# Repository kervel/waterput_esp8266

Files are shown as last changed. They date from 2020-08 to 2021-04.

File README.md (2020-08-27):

# About

This is a simple breakout for an ESP12MOD module that enables easy connection to a 5V power supply and that converts 2 IOs to 5V levels, suitable for connecting an acoustic waterlevel sensor.

The software reads the acoustic waterlevel sensor 30 times and sends the median value via MQTT.

# The hardware

Following components are needed:
* the pcb's (Aisler template is used in pcb/ folder, so easiest to order via aisler)
* an ESP12MOD module (the one with 22 pins!)
* A SR04M-2 acoustic sensor or equivalent
* A LM1117T linear regulator in a TO-220-3 package
* 8 10Kohm 0805 resistors
* 2 BSS138 mosfets in SOT-23 package
* A screw terminal block with 2 connections pitch 3.5mm
* A 0.1μF radial electrolytic capacitor, diameter 4mm, pitch 2mm
* 2 10μF radial electrolytic capacitors, diameter 4mm, pitch 2mm
* female pin header, 6 pins, 2.54mm pitch
* male pin header, 4 pins, 2.54mm pitch for reset/program jumper (optional)
* a jumper or a jumper cable (optional)

To connect the acoustic sensor, note that the `TRG` pin might be called `RX`
and the `ECHO` pin might be called `TX`. This is because some boards can be
configured to operate in serial mode by adding a resistor.

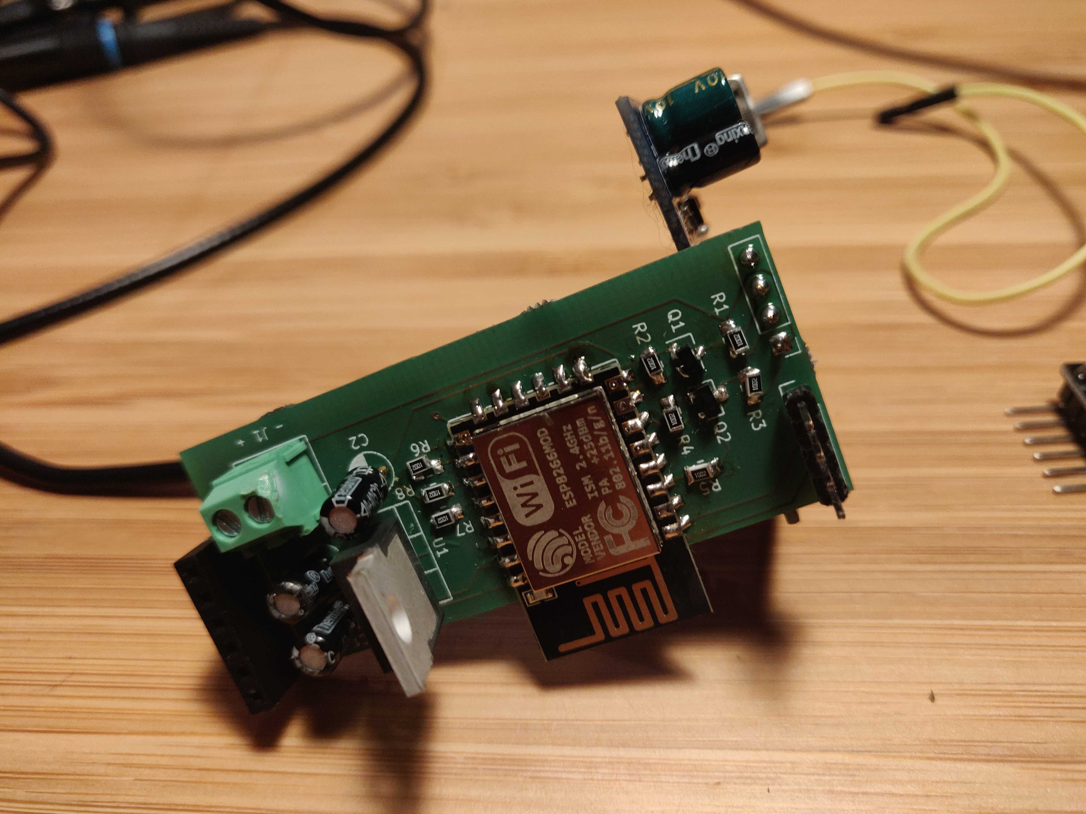
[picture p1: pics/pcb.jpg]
pcb The assembled PCB


# Uploading the firmware

Use platformIO to build it. To upload it, ground the "PRG" pin on the board by connecting a jumper between the PRG and the GND pins, and connect a FTDI module to the female pin header (check the pin-out: 5V must match 5V and GND must match GND, and RX of the board must be connected with TX of the FTDI and vice versa).

After connecting the module, uploading the software should be possible with control-shift-P

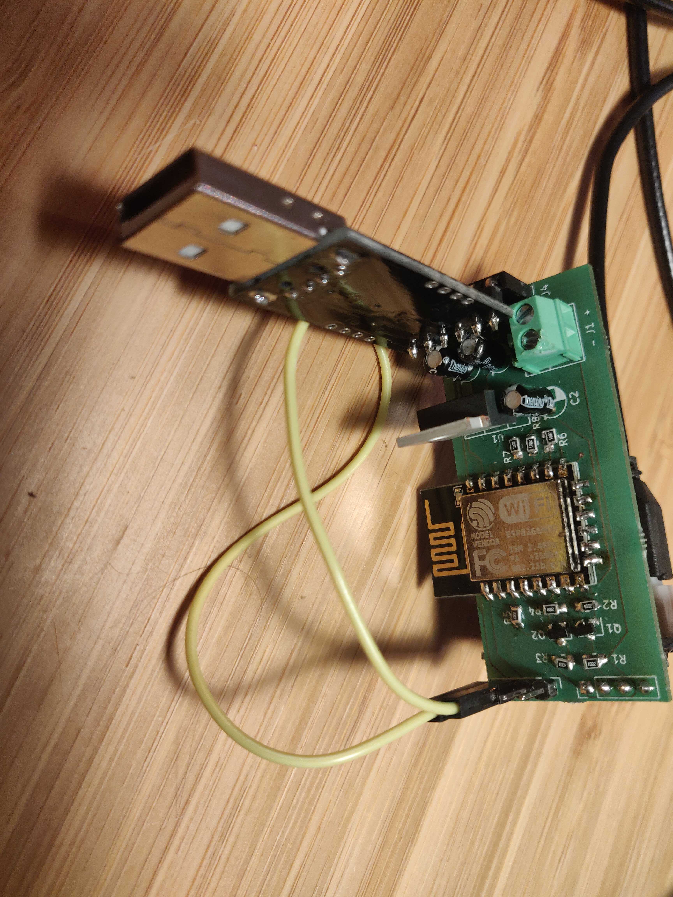
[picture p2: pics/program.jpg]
program Programming the PCB


# Configuring the firmware

Unplug the programming jumper and supply 5V or connect the FTDI again (the PCB can take power from the FTDI, but make sure to unplug/replug to trigger a reboot after programming). Now an access point should become availabe. Connect to it with your android phone, a web interface will pop up where you can set the wifi parameters and the mqtt server.

Write down the chip ID (which is equal to the access point name). After configuration is done the chip will connect to the MQTT server and it will publish some topics:

* `/[chip_id]/online` will contain the number of iterations since boot-up, or will equal "0" if the module is offline
* `/[chip_id]/state` will contain the distance

Every time information is sent to MQTT, the LED will flash briefly 3 times.

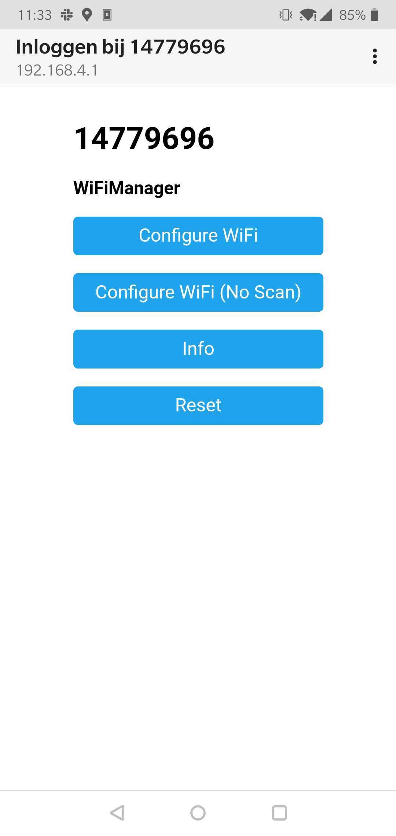
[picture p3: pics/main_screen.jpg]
main_screen Main screen

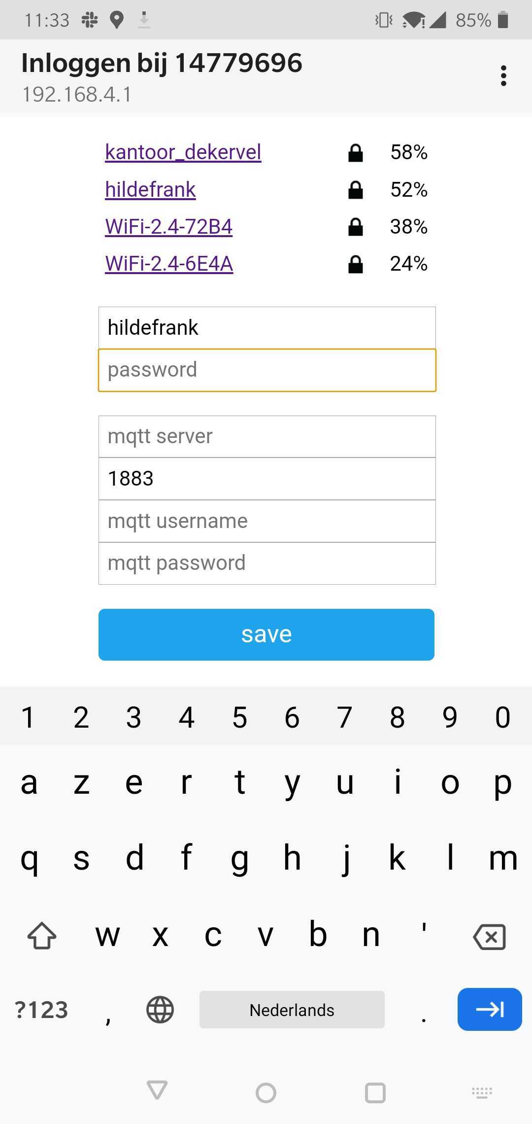
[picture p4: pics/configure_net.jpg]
configure_net Configure network


# Firmware factory reset

Power up the firmware, and *while powered up* connect a jumper between PRG and GND pins. The blue LED will immediately blink 10 times and all settings will be cleared.
Note that this *will not work* if you already connect the jumper cable
before powerup, because then the board will enter firmware download mode.

# Data logging on kubernetes

The k8s subdirectory contains resources for:
* a MQTT server
* influxdb
* telegraf configured to log everything from the MQTT server to influxdb
* grafana

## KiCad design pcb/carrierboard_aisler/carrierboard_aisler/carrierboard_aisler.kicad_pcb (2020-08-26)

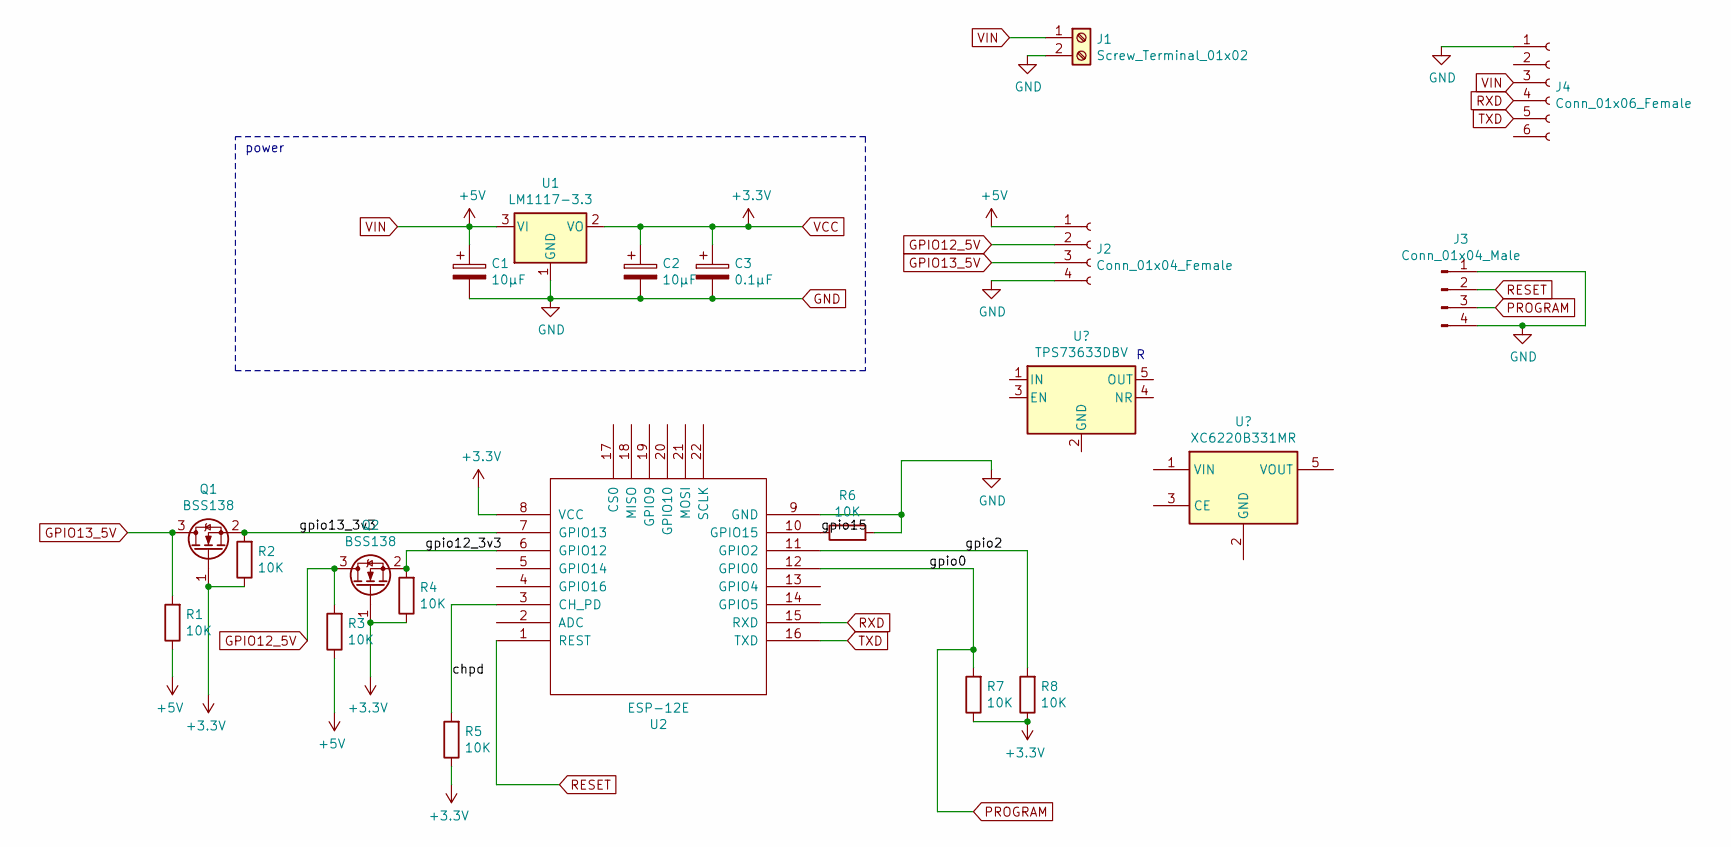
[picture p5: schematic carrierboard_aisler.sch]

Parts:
C1, C2: 10μF; CP_Radial_D4.0mm_P2.00mm
C3: 0.1μF; CP_Radial_D4.0mm_P2.00mm
J1: Screw_Terminal_01x02; TerminalBlock_4Ucon_1x02_P3.50mm_Vertical
J2: Conn_01x04_Female; PinHeader_1x04_P2.54mm_Vertical
J3: Conn_01x04_Male; PinHeader_1x04_P2.54mm_Vertical
J4: Conn_01x06_Female; PinHeader_1x06_P2.54mm_Vertical
Q1, Q2: BSS138; SOT-23
R1, R2, R3, R4, R5, R6, R7, R8: 10K; R_0805_2012Metric_Pad1.15x1.40mm_HandSolder
U1: LM1117-3.3; TO-220-3_Vertical
U2: ESP-12E; ESP-12E_SMD

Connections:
/chpd: R5.2, U2.3 (CH_PD)
/gpio2: R8.2, U2.11 (GPIO2)
/gpio12_3v3: Q2.2 (S), R4.2, U2.6 (GPIO12)
/gpio13_3v3: Q1.2 (S), R2.2, U2.7 (GPIO13)
/gpio15: R6.1, U2.10 (GPIO15)
GND: C1.2, C2.2, C3.2, J1.2, J2.4, J3.1, J3.4, J4.1, R6.2, U1.1 (GND), U2.9 (GND)
GPIO12_5V: J2.2, Q2.3 (D), R3.2
GPIO13_5V: J2.3, Q1.3 (D), R1.2
PROGRAM: J3.3, R7.2, U2.12 (GPIO0)
RESET: J3.2, U2.1 (REST)
RXD: J4.4, U2.15 (RXD)
TXD: J4.5, U2.16 (TXD)
VCC: C2.1, C3.1, Q1.1 (G), Q2.1 (G), R2.1, R4.1, R5.1, R7.1, R8.1, U1.2 (VO), U2.8 (VCC)
VIN: C1.1, J1.1, J2.1, J4.3, R1.1, R3.1, U1.3 (VI)

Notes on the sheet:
power

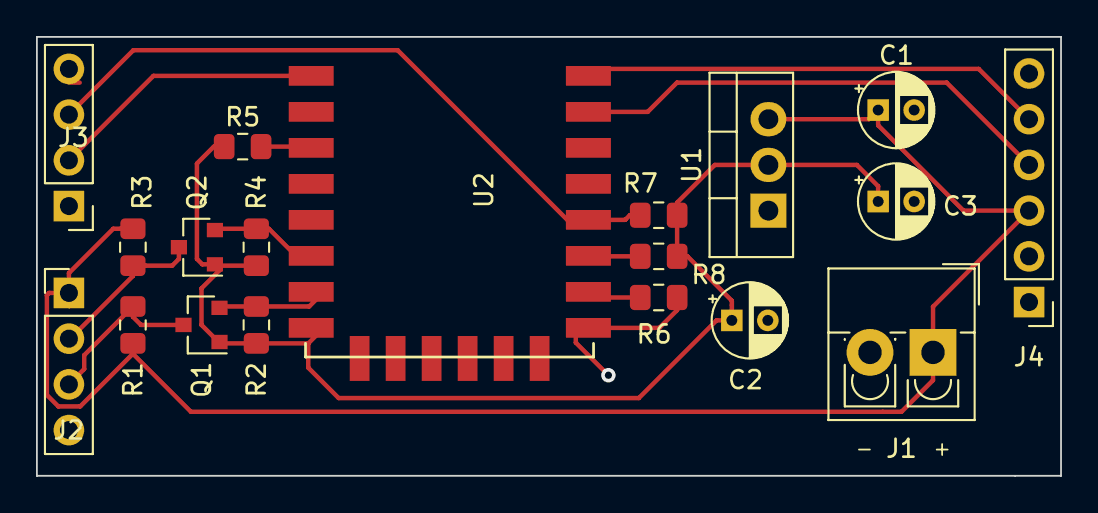
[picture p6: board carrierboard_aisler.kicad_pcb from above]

Board: 2 copper layers, 56.9 x 24.4 mm, 19 parts (0 on the bottom side), 14 nets.

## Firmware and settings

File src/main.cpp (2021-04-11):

#define SERIAL_NUMBER "wl_000001"
#include "ultrasensor.h"
#include "wifi_mgmt.h"
// fwd declarations
void setup_wifi();

unsigned int maxRetries = 20;

WiFiClient espClient;
std::shared_ptr<PubSubClient> client;

void callback(char *topic, byte *payload, unsigned int length) {
  /*Serial.print("Message arrived [");
  Serial.print(topic);
  Serial.print("] ");
  for (unsigned int i = 0; i < length; i++) {
    Serial.print((char)payload[i]);
  }
  Serial.println();*/
}

double state, oldState;
long int loopCount, localLoop;

#define MEAS_INT 30
double measurements[MEAS_INT];

void setup() {
  oldState = -1;
  state = -1;
  loopCount = 0;
  localLoop = 0;
  Serial.begin(9600);
  pinMode(GPIO0, INPUT);
  pinMode(GPIO2, OUTPUT);
  digitalWrite(GPIO2, 1);
  setup_sermode();
  setup_wifi();
  for (int i = 0; i < MEAS_INT; i++) {
    measurements[i] = 0;
  }
}


void setup_wifi() {
  delay(10);
  // We start by connecting to a WiFi network
  client = setup_wifi_and_mqtt(callback);
  // pinMode(LED_BUILTIN, OUTPUT);

  Serial.println("");
  Serial.println("WiFi connected");
  Serial.println("IP address: ");
  Serial.println(WiFi.localIP());
}

void reconnect() {
  if (!WiFi.isConnected()) {
    Serial.println("wifi connection lost, rebooting");
    ESP.restart();
  }
  if (!client->connected()) {
    Serial.print("MQTT connection lost, rebooting...");
    ESP.restart();
  }
}

int cmpfunc(const void *a, const void *b) {
  return (*(double *)a - *(double *)b);
}

void loop() {
  char charBuf[50];
  reconnect();

  if (maxRetries == 0) {
    Serial.println("too many failures sending, restart");
    ESP.restart();
  }

  loopCount += 1;

  check_reset_pin();


  // take the maximum distance found. other distances are probably noise
  if (localLoop >= MEAS_INT) {
    localLoop = 0;
    qsort(measurements, MEAS_INT, sizeof(double), cmpfunc);
    state = measurements[MEAS_INT / 2];
    Serial.print("got new state ");
    Serial.print(state);
    Serial.println("..");

    if ((state != oldState) && (state > 0)) {
      if (!client->publish(unique_topic("state").c_str(),
                           String(state).c_str())) {
        maxRetries -= 1;
      }
      blink(3, 100);
      oldState = state;
    }
    state = -1;
    for (int i = 0; i < MEAS_INT; i++) {
      measurements[i] = 0;
    }
  } else {
    double newState = getdist_triggermode();
    if (newState > 0) {
      measurements[localLoop] = newState;
      localLoop += 1;
      Serial.print("[");
      Serial.print(localLoop);
      Serial.print("]=");
      Serial.println(newState);
    }
  }
  if (loopCount % 600 == 0) {
    ltoa(loopCount, charBuf, 10);
    if (!client->publish(online_topic().c_str(), charBuf, true)) {
      maxRetries -= 1;
    }
  }
  client->loop();
}

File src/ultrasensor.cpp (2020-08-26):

#include "ultrasensor.h"
SoftwareSerial sensor; // RX = echoPin

void setup_sermode() {
  sensor.begin(9600,SWSERIAL_8N1, echoPin, pingPin, false, 16536, 4096);
}

void setup_triggermode() {
  pinMode(pingPin, OUTPUT);
  pinMode(echoPin, INPUT);
  Serial.begin(9600);
}

double microsecondsToCentimeters(long microseconds) {
  return ((double)(microseconds)) / 29.0 / 2.0;
}


double getdist_triggermode() {
  long duration, duration2;
  double cm;
  digitalWrite(pingPin, LOW);
  delayMicroseconds(2);
  digitalWrite(pingPin, HIGH);
  delayMicroseconds(10);
  digitalWrite(pingPin, LOW);
  duration = pulseIn(echoPin, HIGH);
  //duration2 = pulseIn(echoPin, LOW);
  if (duration > 50000) {
      return 0;
  }
  cm = microsecondsToCentimeters(duration);
  //Serial.print("microsecs: ");
  //Serial.println(duration);
  //Serial.println(duration2);
  delay(100);
  return cm;
}


// source:
// http://www.setfirelabs.com/building-automation/dyp-me007y-tx-serial-output-ultrasonic-sensor-interfacing-with-arduino-nodemcu
double getdist_sermode() {
  byte msb, lsb, checksum, checkcalc, tries = 0;
  int distance;

  // we want a 255 which is the start of the reading (not msb but saving a byte
  // of variable storage)..
  while (msb != 255) {
    // wait for serial..
    while (not sensor.available() && tries < MAX_TRY_SERIAL) {
      delay(10);
      tries++;
    }
    if (tries == MAX_TRY_SERIAL) {
      Serial.println(" TIMED OUT WAITING FOR SERIAL.");
      return -1;
    }
    msb = sensor.read();
  }

  // now we collect MSB, LSB, Checksum..
  while (not sensor.available()) {
    delay(10);
  }
  msb = sensor.read();

  while (not sensor.available()) {
    delay(10);
  }
  lsb = sensor.read();

  while (not sensor.available()) {
    delay(10);
  }
  checksum = sensor.read();

  // is the checksum ok?
  checkcalc = 255 + msb + lsb;

  if (checksum == checkcalc) {
    distance = msb * 256 + lsb;
    // Round from mm to cm
    distance += 5;
    distance = distance / 10;

    return distance;
  } else {
    Serial.println("bad checksum - ignoring reading.");
    return -1;
  }

} // end of GetDistance()
